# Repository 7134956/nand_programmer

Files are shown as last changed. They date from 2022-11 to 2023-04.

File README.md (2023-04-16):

# NANDO (NANDopen) programmer

## General
NANDO is open source NAND programmer based on low cost MCU CH32V307VCT6. It supports parallel NAND, SPI NOR, SPI NAND programming.
High programming speed! For examle EM73C044SNB (1Gb) Write 110(s), Read 80(s).

PCB boards:

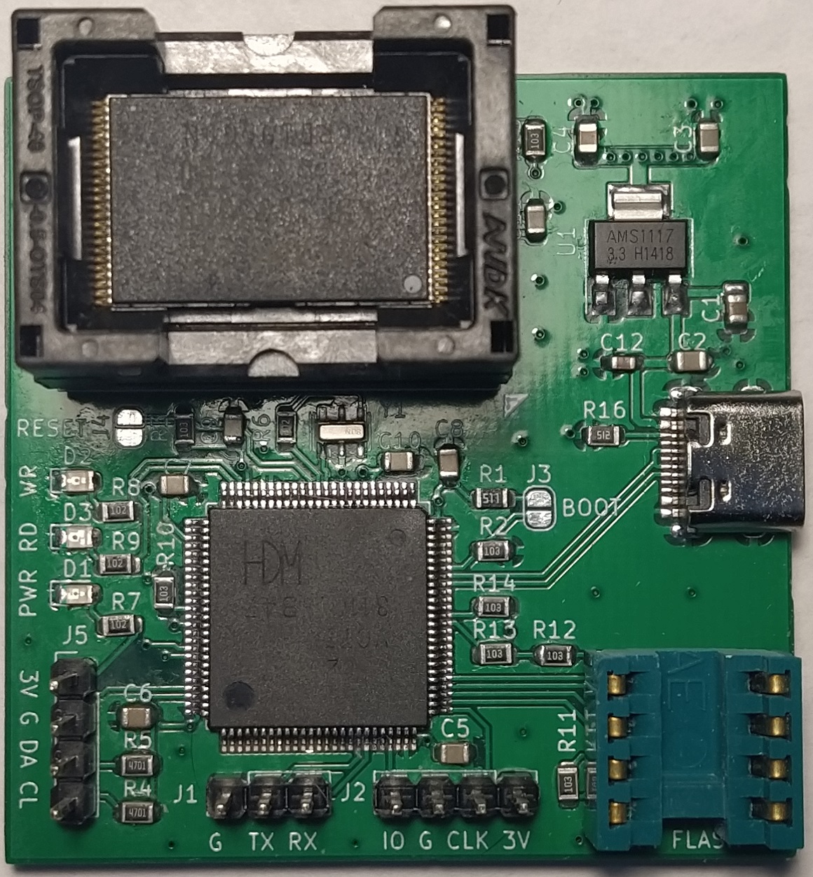
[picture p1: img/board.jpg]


Application:

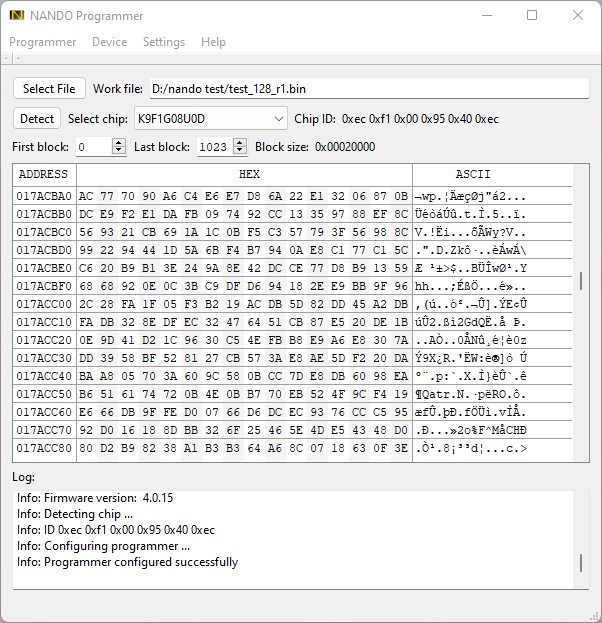
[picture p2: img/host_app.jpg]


## Features
- USB_HS interface
- PC client software for Linux & Windows.
- TSOP-48 socket for NAND chip
- 8 bit parallel NAND interface
- SPI interface
- 3.3V NAND power supply
- NAND read,write and erase support
- NAND read of chip ID support
- NAND read of bad blocks
- NAND bad block skip option
- NAND include spare area option
- Configurable erase, write, read areas.
- Open KiCad PCB & Schematic
- Open source code
- Read & Write LEDs indication
- Extendable chip database
- Chip autodetection
- Firmware update

### Supported chips
#### Parallel NAND:
K9F2G08U0C, HY27US08121B, TC58NVG2S3E, F59L2G81A, MX30LF2G18AC and others.

See full list of supported chips [qt/nando_parallel_chip_db.csv](qt/nando_parallel_chip_db.csv)

#### SPI NOR flash
AT45DB021D, MX25L8006E, W25Q16JV and others.

See full list of supported chips [qt/nando_spi_nor_db.csv](qt/nando_spi_nor_db.csv)

#### SPI NAND flash
GD5F1GQ4UBxIG, MT29F2G01, F50L2G41LB and others.

See full list of supported chips [qt/nando_spi_nand_db.csv](qt/nando_spi_nand_db.csv)

## Release binaries
...

### License
In general the sorce code, PCB and schematic are under GPLv3 license but with limitations of:

## WiKi
Check [WiKi](https://github.com/bbogush/nand_programmer/wiki) page for more information.

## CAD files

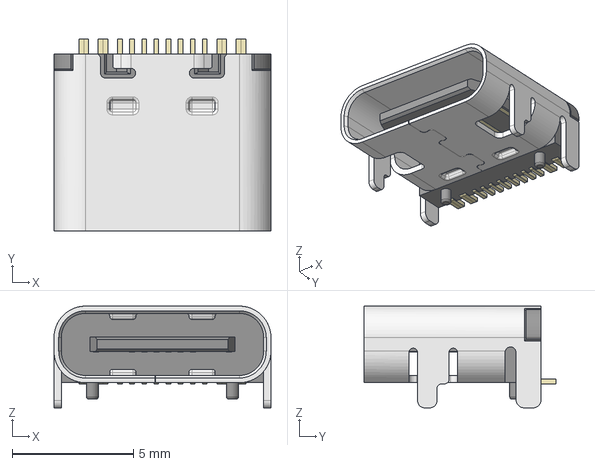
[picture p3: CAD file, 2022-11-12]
kicad/3D/HRO_TYPE-C-31-M-12.step
8.95 x 7.90 x 4.20 mm

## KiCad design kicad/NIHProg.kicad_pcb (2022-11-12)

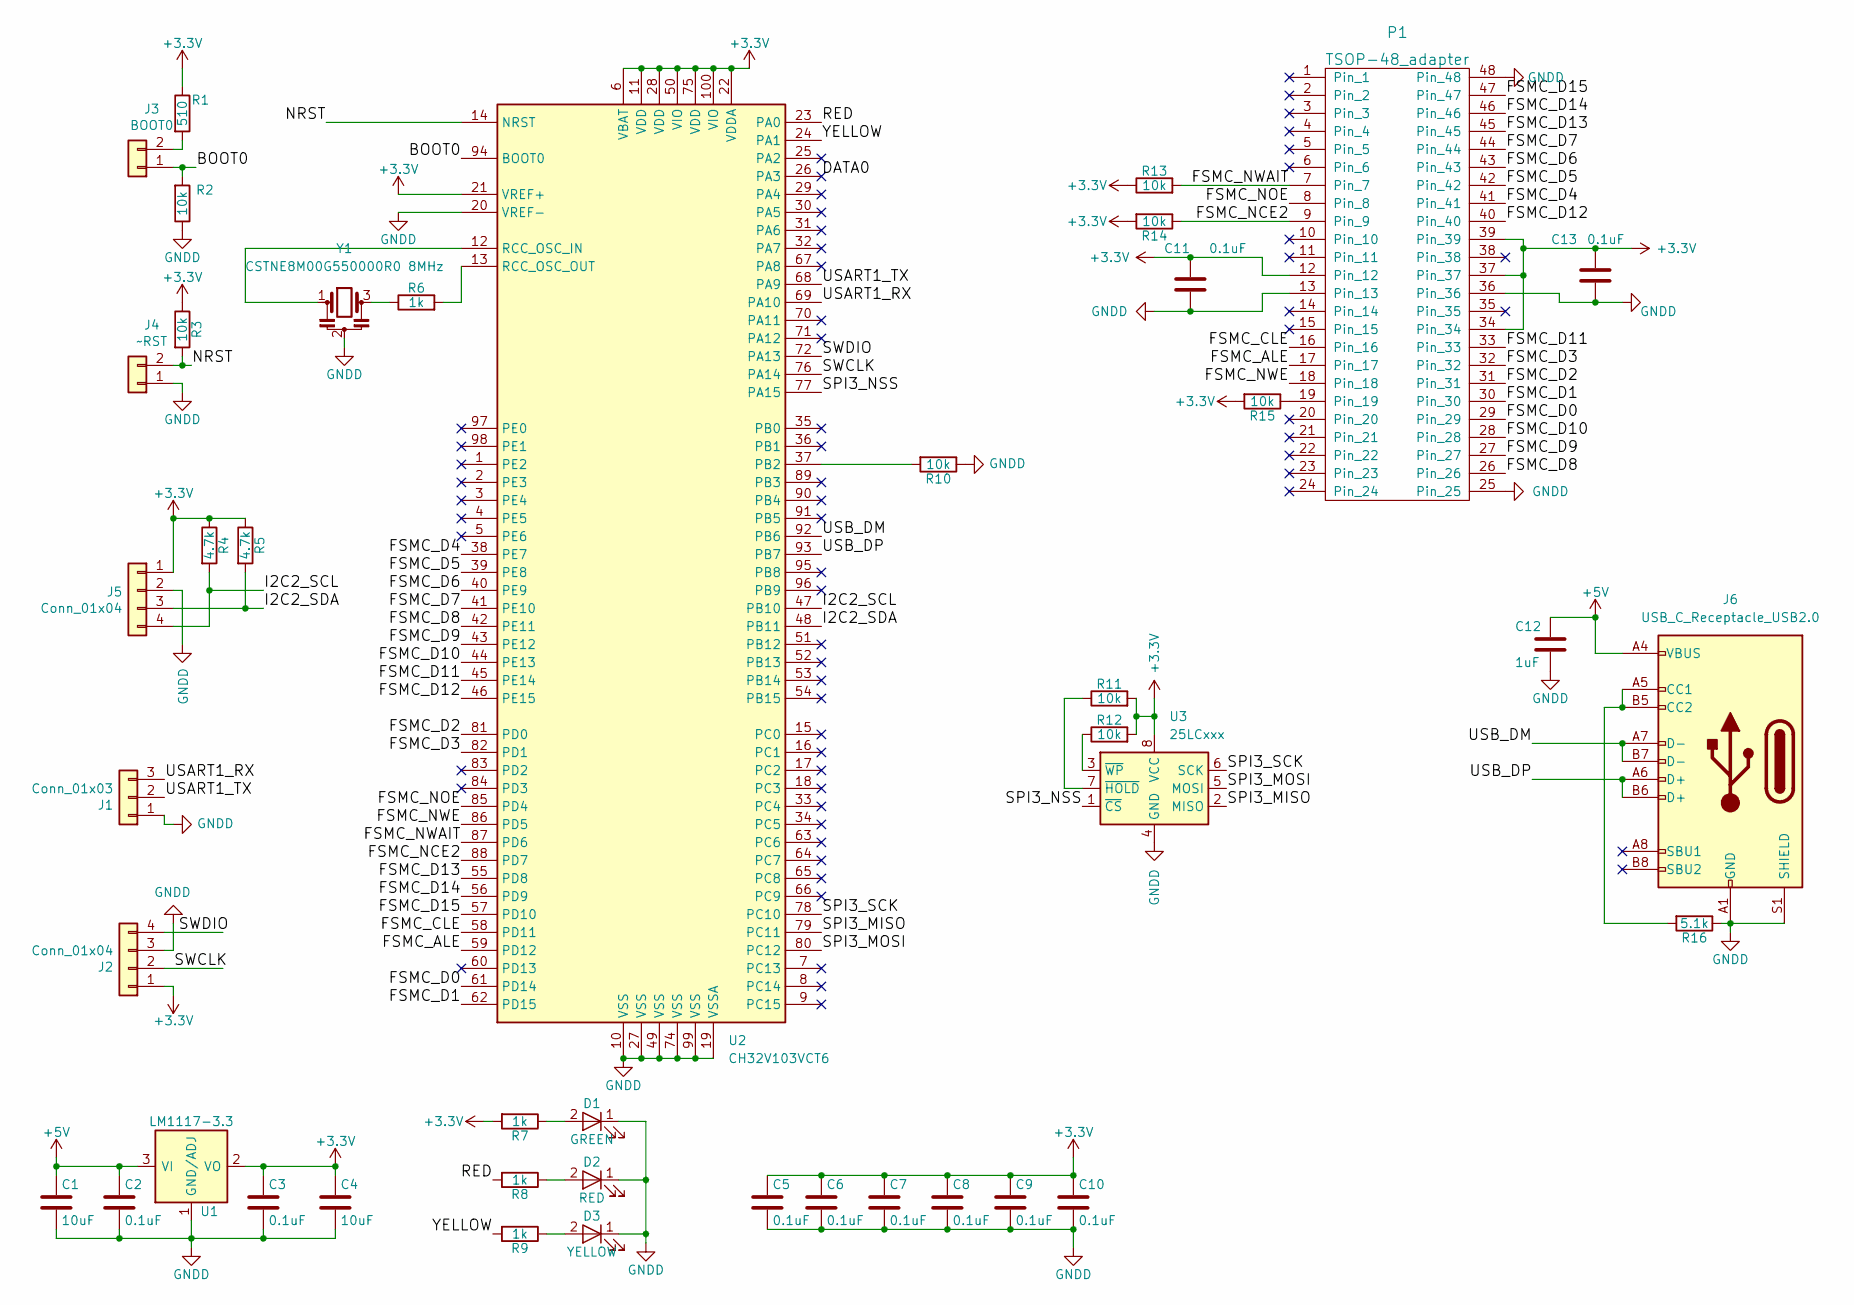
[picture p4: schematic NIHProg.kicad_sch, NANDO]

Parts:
C1, C4: 10uF; C_0805_2012Metric_Pad1.18x1.45mm_HandSolder; Farnell Ref 2112850
C2, C3, C5, C6, C7, C8, C9, C10, C11, C13: 0.1uF; C_0603_1608Metric_Pad1.08x0.95mm_HandSolder; Farnell Ref 2320839
C12: 1uF; C_0603_1608Metric_Pad1.08x0.95mm_HandSolder; Farnell Ref 2320839
D1: GREEN; LED_0603_1608Metric_Pad1.05x0.95mm_HandSolder; Farnell Ref 2099239
D2: RED; LED_0603_1608Metric_Pad1.05x0.95mm_HandSolder; Farnell Ref 2099236
D3: YELLOW; LED_0603_1608Metric_Pad1.05x0.95mm_HandSolder; Farnell Ref 2099243
J1: Conn_01x03; PinHeader_1x03_P2.54mm_Vertical; Farnell Ref 3049527
J2, J5: Conn_01x04; PinHeader_1x04_P2.54mm_Vertical; Farnell Ref 3049529
J3: BOOT0; SolderJumper-2_P1.3mm_Open_RoundedPad1.0x1.5mm
J4: ~RST; SolderJumper-2_P1.3mm_Open_RoundedPad1.0x1.5mm
J6: USB_C_Receptacle_USB2.0; TYPE-C-31-M-12; MPN TYPE-C-31-M-17
P1: TSOP-48_adapter; TSOP48ZIF
R1: 510; R_0603_1608Metric_Pad0.98x0.95mm_HandSolder; Farnell Ref 2447679
R2, R3, R10, R11, R12, R13, R14, R15: 10k; R_0603_1608Metric_Pad0.98x0.95mm_HandSolder; Farnell Ref 2447553
R4, R5: 4.7k; R_0603_1608Metric_Pad0.98x0.95mm_HandSolder; Farnell Ref 2447553
R6: 1k; R_0603_1608Metric_Pad0.98x0.95mm_HandSolder; Farnell Ref 2447553
R7, R8, R9: 1k; R_0603_1608Metric_Pad0.98x0.95mm_HandSolder; Farnell Ref 2447587
R16: 5.1k; R_0603_1608Metric_Pad0.98x0.95mm_HandSolder; Farnell Ref 2447587
U1: LM1117-3.3; SOT-223; Farnell Ref 3007498
U2: CH32V103VCT6; LQFP-100_14x14mm_P0.5mm
U3: 25LCxxx; DIP-8_W7.62mm_Socket
Y1: CSTNE8M00G550000R0 8MHz; Resonator_SMD_Murata_CSTxExxV-3Pin_3.0x1.1mm_HandSoldering

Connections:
+3V3: C3.1, C4.1, C5.1, C6.1, C7.1, C8.1, C9.1, C10.1, C11.1, C13.1, J2.1, J5.1, P1.12, P1.34, P1.37, P1.39, R1.1, R3.1, R4.1, R5.1, R7.2, R11.2, R12.2, R13.1, R14.2, R15.2, U1.2 (VO), U1.4 (VO), U2.6 (VBAT), U2.11 (VDD), U2.21 (VREF+), U2.22 (VDDA), U2.28 (VDD), U2.50 (VIO), U2.75 (VDD), U2.100 (VIO), U3.8 (VCC)
+5V: C1.1, C2.1, C12.1, J6.A4 (VBUS), J6.A9 (VBUS), J6.B4 (VBUS), J6.B9 (VBUS), U1.3 (VI)
/BOOT0: J3.1, R2.2, U2.94 (BOOT0)
/DATA0: U2.26 (PA3)
/FSMC_ALE: P1.17, U2.59 (PD12)
/FSMC_CLE: P1.16, U2.58 (PD11)
/FSMC_D0: P1.29, U2.61 (PD14)
/FSMC_D1: P1.30, U2.62 (PD15)
/FSMC_D2: P1.31, U2.81 (PD0)
/FSMC_D3: P1.32, U2.82 (PD1)
/FSMC_D4: P1.41, U2.38 (PE7)
/FSMC_D5: P1.42, U2.39 (PE8)
/FSMC_D6: P1.43, U2.40 (PE9)
/FSMC_D7: P1.44, U2.41 (PE10)
/FSMC_D8: P1.26, U2.42 (PE11)
/FSMC_D9: P1.27, U2.43 (PE12)
/FSMC_D10: P1.28, U2.44 (PE13)
/FSMC_D11: P1.33, U2.45 (PE14)
/FSMC_D12: P1.40, U2.46 (PE15)
/FSMC_D13: P1.45, U2.55 (PD8)
/FSMC_D14: P1.46, U2.56 (PD9)
/FSMC_D15: P1.47, U2.57 (PD10)
/FSMC_NCE2: P1.9, R14.1, U2.88 (PD7)
/FSMC_NOE: P1.8, U2.85 (PD4)
/FSMC_NWAIT: P1.7, R13.2, U2.87 (PD6)
/FSMC_NWE: P1.18, U2.86 (PD5)
/I2C2_SCL: J5.4, R4.2, U2.47 (PB10)
/I2C2_SDA: J5.3, R5.2, U2.48 (PB11)
/NRST: J4.2, R3.2, U2.14 (NRST)
/RED: R8.2, U2.23 (PA0)
/SPI3_MISO: U2.79 (PC11), U3.2 (MISO)
/SPI3_MOSI: U2.80 (PC12), U3.5 (MOSI)
/SPI3_NSS: U2.77 (PA15), U3.1 (~CS)
/SPI3_SCK: U2.78 (PC10), U3.6 (SCK)
/SWCLK: J2.2, U2.76 (PA14)
/SWDIO: J2.4, U2.72 (PA13)
/USART1_RX: J1.3, U2.69 (PA10)
/USART1_TX: J1.2, U2.68 (PA9)
/USB_DM: J6.A7 (D-), J6.B7 (D-), U2.92 (PB6)
/USB_DP: J6.A6 (D+), J6.B6 (D+), U2.93 (PB7)
/YELLOW: R9.2, U2.24 (PA1)
GNDD: C1.2, C2.2, C3.2, C4.2, C5.2, C6.2, C7.2, C8.2, C9.2, C10.2, C11.2, C12.2, C13.2, D1.1 (K), D2.1 (K), D3.1 (K), J1.1, J2.3, J4.1, J5.2, J6.A1 (GND), J6.A12 (GND), J6.B1 (GND), J6.B12 (GND), J6.S1 (SHIELD), P1.13, P1.25, P1.36, P1.48, R2.1, R10.1, R16.1, U1.1 (GND/ADJ), U2.10 (VSS), U2.19 (VSSA), U2.20 (VREF-), U2.27 (VSS), U2.49 (VSS), U2.74 (VSS), U2.99 (VSS), U3.4 (GND), Y1.2
unnamed: D1.2 (A), R7.1
unnamed: D2.2 (A), R8.1
unnamed: D3.2 (A), R9.1
unnamed: J3.2, R1.2
unnamed: J6.A5 (CC1), J6.B5 (CC2), R16.2
unnamed: P1.19, R15.1
unnamed: R6.1, Y1.3
unnamed: R6.2, U2.13 (RCC_OSC_OUT)
unnamed: R10.2, U2.37 (PB2)
unnamed: R11.1, U3.7 (~HOLD)
unnamed: R12.1, U3.3 (~WP)
unnamed: U2.12 (RCC_OSC_IN), Y1.1

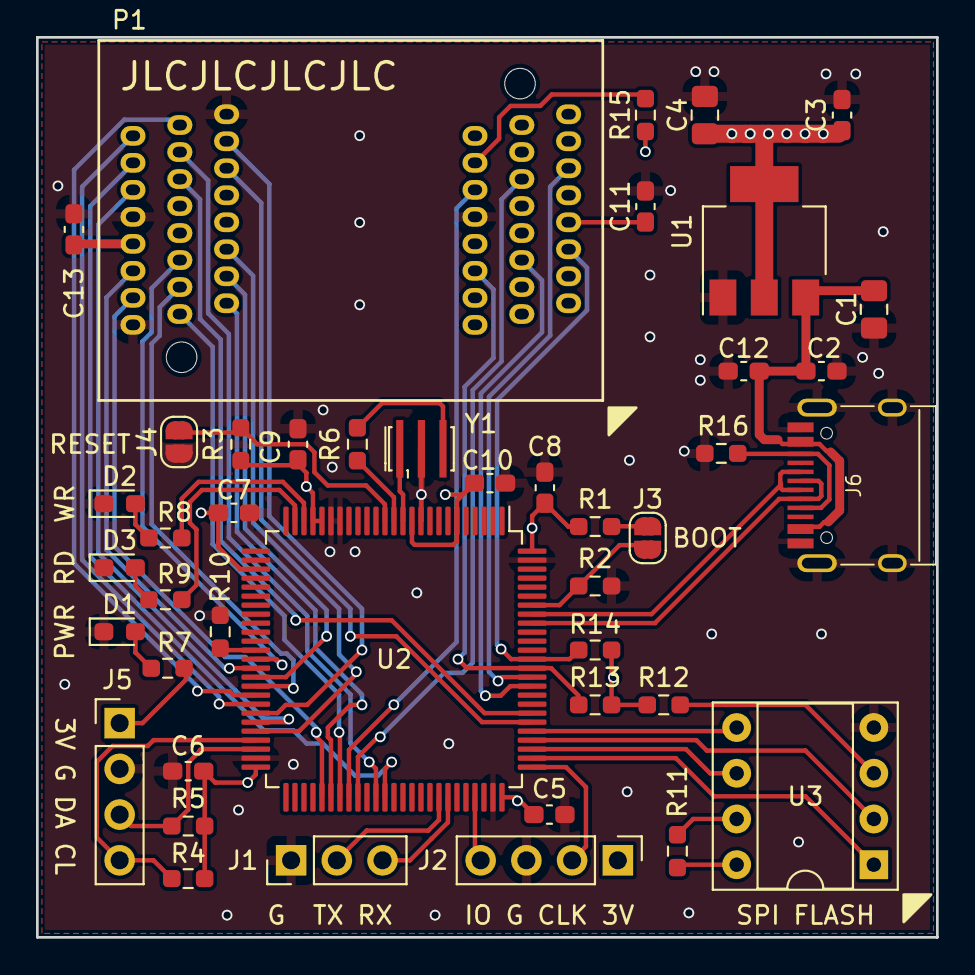
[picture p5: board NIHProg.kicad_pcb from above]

Board: 4 copper layers, 50.0 x 50.0 mm, 43 parts (0 on the bottom side), 53 nets.

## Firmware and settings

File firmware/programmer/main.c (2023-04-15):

/*  Copyright (C) 2020 NANDO authors
 *  This program is free software; you can redistribute it and/or modify
 *  it under the terms of the GNU General Public License version 3.
 */

#include "nand_programmer.h"
#include "cdc.h"
#include "led.h"
#include "uart.h"
#include "jtag.h"
#include "version.h"
#include "clock.h"
#include <stdio.h>

int main()
{
    uart_init();
    printf("\r\nNAND programmer ver: %d.%d.%d\r\n", SW_VERSION_MAJOR,
        SW_VERSION_MINOR, SW_VERSION_BUILD);

    if (!is_external_clock_avail())
        printf("External clock not detected. Fallback to internal clock.\r\n");

    printf("JTAG init...");
    jtag_init();
    printf("done.\r\n");

    printf("LED init...");
    led_init();
    printf("done.\r\n");

    printf("CDC init...");
    cdc_init();
    printf("done.\r\n");

    printf("Programmer init...");
    np_init();
    printf("done.\r\n");

    while (1)
        np_handler();

    return 0;
}

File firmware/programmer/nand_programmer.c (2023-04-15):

/*  Copyright (C) 2020 NANDO authors
 *  This program is free software; you can redistribute it and/or modify
 *  it under the terms of the GNU General Public License version 3.
 */

#include "nand_programmer.h"
#include "nand_bad_block.h"
#include "fsmc_nand.h"
#include "chip_info.h"
#include "led.h"
#include "log.h"
#include "version.h"
#include "flash.h"
#include "spi_nor_flash.h"
#include "spi_nand_flash.h"
#include <stdio.h>
#include <string.h>
#include <stddef.h>
#include <stdbool.h>
#include <inttypes.h>

#define NP_PACKET_BUF_SIZE 512
#define NP_MAX_PAGE_SIZE 0x21C0 /* 8KB + 448 spare */
#define NP_WRITE_ACK_BYTES 1984
#define NP_NAND_TIMEOUT 0x1000000

#define NP_NAND_GOOD_BLOCK_MARK 0xFF

#define BOOT_CONFIG_ADDR 0x08003800
#define FLASH_START_ADDR 0x08000000
#define FLASH_SIZE 0x40000
#define FLASH_PAGE_SIZE 0x100
#define FLASH_BLOCK_SIZE 0x100

typedef enum
{
    NP_CMD_NAND_READ_ID     = 0x00,
    NP_CMD_NAND_ERASE       = 0x01,
    NP_CMD_NAND_READ        = 0x02,
    NP_CMD_NAND_WRITE_S     = 0x03,
    NP_CMD_NAND_WRITE_D     = 0x04,
    NP_CMD_NAND_WRITE_E     = 0x05,
    NP_CMD_NAND_CONF        = 0x06,
    NP_CMD_NAND_READ_BB     = 0x07,
    NP_CMD_VERSION_GET      = 0x08,
    NP_CMD_ACTIVE_IMAGE_GET = 0x09,
    NP_CMD_FW_UPDATE_S      = 0x0a,
    NP_CMD_FW_UPDATE_D      = 0x0b,
    NP_CMD_FW_UPDATE_E      = 0x0c,
    NP_CMD_NAND_LAST        = 0x0d,
} np_cmd_code_t;

enum
{
    NP_ERR_INTERNAL       = -1,
    NP_ERR_ADDR_EXCEEDED  = -100,
    NP_ERR_ADDR_INVALID   = -101,
    NP_ERR_ADDR_NOT_ALIGN = -102,
    NP_ERR_NAND_WR        = -103,
    NP_ERR_NAND_RD        = -104,
    NP_ERR_NAND_ERASE     = -105,
    NP_ERR_CHIP_NOT_CONF  = -106,
    NP_ERR_CMD_DATA_SIZE  = -107,
    NP_ERR_CMD_INVALID    = -108,
    NP_ERR_BUF_OVERFLOW   = -109,
    NP_ERR_LEN_NOT_ALIGN  = -110,
    NP_ERR_LEN_EXCEEDED   = -111,
    NP_ERR_LEN_INVALID    = -112,
    NP_ERR_BBT_OVERFLOW   = -113,
};

typedef struct __attribute__((__packed__))
{
    uint8_t code;
} np_cmd_t;

typedef struct __attribute__((__packed__))
{
    uint8_t skip_bb : 1;
    uint8_t inc_spare : 1;
    uint8_t enable_hw_ecc: 1;
} np_cmd_flags_t;

typedef struct __attribute__((__packed__))
{
    np_cmd_t cmd;
    uint64_t addr;
    uint64_t len;
    np_cmd_flags_t flags;
} np_erase_cmd_t;

typedef struct __attribute__((__packed__))
{
    np_cmd_t cmd;
    uint64_t addr;
    uint64_t len;
    np_cmd_flags_t flags;
} np_write_start_cmd_t;

typedef struct __attribute__((__packed__))
{
    np_cmd_t cmd;
    uint16_t len;
    uint8_t data[];
} np_write_data_cmd_t;

typedef struct __attribute__((__packed__))
{
    np_cmd_t cmd;
} np_write_end_cmd_t;

typedef struct __attribute__((__packed__))
{
    np_cmd_t cmd;
    uint64_t addr;
    uint64_t len;
    np_cmd_flags_t flags;
} np_read_cmd_t;

typedef struct __attribute__((__packed__))
{
    np_cmd_t cmd;
    uint8_t hal;
    uint32_t page_size;
    uint32_t block_size;
    uint64_t total_size;
    uint32_t spare_size;    
    uint8_t bb_mark_off;
    uint8_t hal_conf[];
} np_conf_cmd_t;

enum
{
    NP_RESP_DATA   = 0x00,
    NP_RESP_STATUS = 0x01,
};

typedef struct __attribute__((__packed__))
{
    uint8_t code;
    uint16_t info;
    uint8_t data[];
} np_resp_t;

enum
{
    NP_STATUS_OK        = 0x00,
    NP_STATUS_ERROR     = 0x01,
    NP_STATUS_BB        = 0x02,
    NP_STATUS_WRITE_ACK = 0x03,
    NP_STATUS_BB_SKIP   = 0x04,
    NP_STATUS_PROGRESS  = 0x05,
};

typedef struct __attribute__((__packed__))
{
    np_resp_t header;
    chip_id_t nand_id;
} np_resp_id_t;

typedef struct __attribute__((__packed__))
{
    np_resp_t header;
    uint64_t addr;
    uint32_t size;
} np_resp_bad_block_t;

typedef struct __attribute__((__packed__))
{
    np_resp_t header;
    uint64_t bytes_ack;
} np_resp_write_ack_t;

typedef struct __attribute__((__packed__))
{
    np_resp_t header;
    uint8_t err_code;
} np_resp_err_t;

typedef struct __attribute__((__packed__))
{
    np_resp_t header;
    uint64_t progress;
} np_resp_progress_t;

typedef struct __attribute__((__packed__))
{
    uint8_t major;
    uint8_t minor;
    uint16_t build;
} version_t;

typedef struct __attribute__((__packed__))
{
    np_resp_t header;
    version_t version;
} np_resp_version_t;

typedef struct __attribute__((__packed__))
{
    np_resp_t header;
    uint8_t active_image;
} np_resp_active_image_t;

typedef struct
{
    uint32_t addr;
    int is_valid;
} np_prog_addr_t;

typedef struct
{
    uint8_t buf[NP_MAX_PAGE_SIZE];
    uint32_t page;
    uint32_t offset;
} np_page_t;

typedef struct __attribute__((__packed__))
{
    uint8_t active_image;
} boot_config_t;

typedef struct
{
    uint8_t *rx_buf;
    uint32_t rx_buf_len;
    uint64_t addr;
    uint64_t len;
    uint64_t base_addr;
    uint32_t page_size;
    uint32_t block_size;
    uint64_t total_size;
    int addr_is_set;
    int bb_is_read;
    int chip_is_conf;
    np_page_t page;
    uint64_t bytes_written;
    uint64_t bytes_ack;
    int skip_bb;
    int nand_wr_in_progress;
    uint32_t nand_timeout;
    chip_info_t chip_info;
    uint8_t active_image;
    uint8_t hal;
} np_prog_t;

typedef struct
{
    int id;
    bool is_chip_cmd;
    int (*exec)(np_prog_t *prog);
} np_cmd_handler_t;

static np_comm_cb_t *np_comm_cb;
static np_prog_t prog;

static flash_hal_t *hal[] = { &hal_fsmc, &hal_spi_nor, &hal_spi_nand };

uint8_t np_packet_send_buf[NP_PACKET_BUF_SIZE];

static int np_send_ok_status()
{
    np_resp_t status = { NP_RESP_STATUS, NP_STATUS_OK };
    size_t len = sizeof(status);

    if (np_comm_cb)
        np_comm_cb->send((uint8_t *)&status, len);

    return 0;
}

static int np_send_error(uint8_t err_code)
{
    np_resp_t status = { NP_RESP_STATUS, NP_STATUS_ERROR };
    np_resp_err_t err_status = { status, err_code };
    size_t len = sizeof(err_status);

    if (np_comm_cb)
        np_comm_cb->send((uint8_t *)&err_status, len);

    return 0;
}

static int np_send_bad_block_info(uint64_t addr, uint32_t size, bool is_skipped)
{
    uint8_t info = is_skipped ? NP_STATUS_BB_SKIP : NP_STATUS_BB;
    np_resp_t resp_header = { NP_RESP_STATUS, info };
    np_resp_bad_block_t bad_block = { resp_header, addr, size };

    if (np_comm_cb->send((uint8_t *)&bad_block, sizeof(bad_block)))
        return -1;

    return 0;
}

static int np_send_progress(uint64_t progress)
{
    np_resp_t resp_header = { NP_RESP_STATUS, NP_STATUS_PROGRESS };
    np_resp_progress_t resp_progress = { resp_header, progress };

    if (np_comm_cb->send((uint8_t *)&resp_progress, sizeof(resp_progress)))
        return -1;

    return 0;
}
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

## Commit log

2022-11-05 Qt: Fix for Qt 6.4.0 + MinGW64
    [main_window.cpp]
2022-11-12 KiCad: Update schematic and board for CH32V307VCT6 MCU.
    [HRO_TYPE-C-31-M-12.step, NIHProg.kicad_pcb, NIHProg.kicad_sch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]
2023-02-18 Qt: Add flash work range support.
    Qt: Fix progress in part mode
    [main_window.cpp]
2023-02-20 firmware: Change SPI1 to SPI3 for new board design.
2023-02-24 DB: SPI: Add W25Q64FV chip.
    [nando_spi_chip_db.csv]
2023-04-15 firmware: Fix typos in debug messages. Unused include in main.c
    [main.c, nand_programmer.c]
2023-04-15 firmware: Fix USB collision.
    [nand_programmer.c]
2023-04-15 Add SPI NAND flash support.
    [nando_spi_nand_db.csv, nando_spi_nor_db.csv]
2023-04-16 Firmware: Use DMA for SPI transfer.
2024-11-17 DB: Adding chips and sorting.
    [nando_parallel_chip_db.csv, nando_spi_nand_db.csv, nando_spi_nor_db.csv]
